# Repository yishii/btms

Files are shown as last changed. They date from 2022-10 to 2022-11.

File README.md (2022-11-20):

# Back To the Meeting Switch (BTMS) 【緊急】会議復帰スイッチ

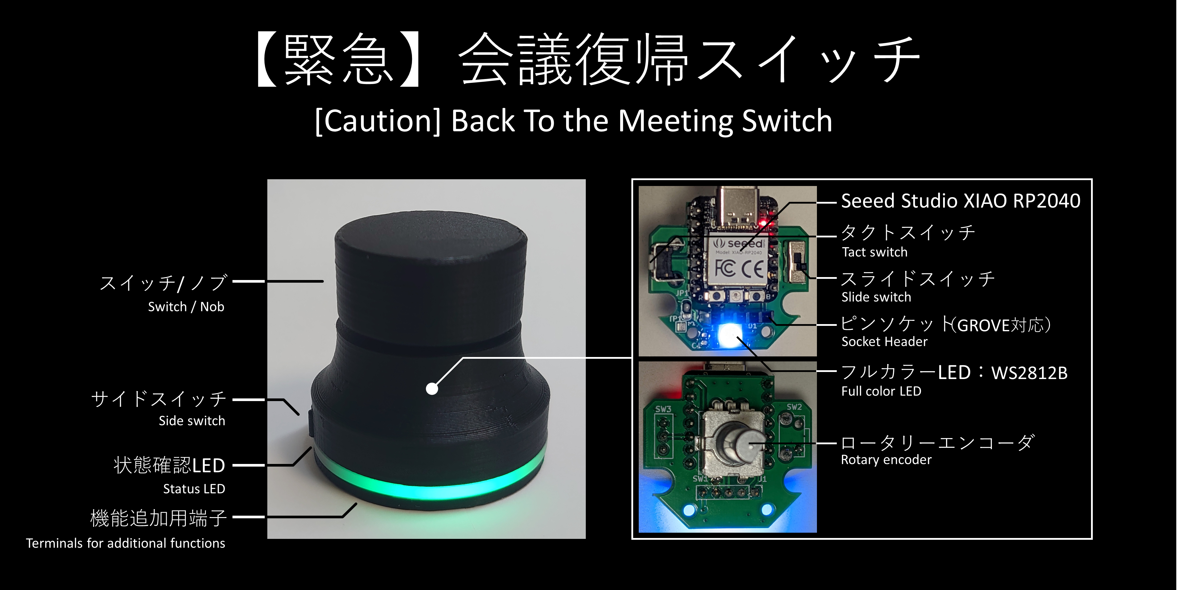
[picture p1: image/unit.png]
BTMS


[[日本語版はこちら]](README_ja.md)

## Back Story
Sometimes happen that attending to the online meeting that roughly just listen to. 
This  is the chance for do editing excel or powerpoints.

But, if suddenly asked some comment unexpectedly, then in panic and cannot back to the meeting right away quickly.

That's why we developed Back To the Meeting Switch(BTMS) for this solution.

With the BTMS, you can turn the knob to select the backgrounded online meeting window, then press the knob the meeting windows comes to the forefront, and at the same time, the MIC mute turns off. And just you do is answer with relax.

So, ~~do another job~~ attend the meeting in peace.

## What is BTMS?

BTMS (Back To the Meeting Switch) is a kind of human interface device that using Seeeduino Xiao (SAMD or RP2040).
With this item, we can get back to online meeting right away even though we're doing other things during the online meeting. This is the main purpose of this device. But this has expansion port (compatible with Grove connector)  at the back side of this device and can easily attach some external button as the Dock of BTMS.

For details, plase watch the video below!

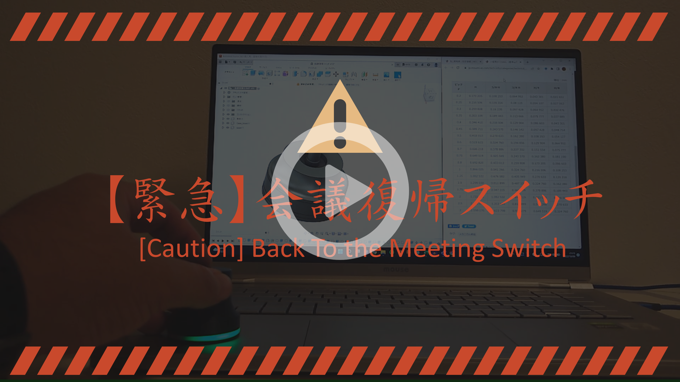
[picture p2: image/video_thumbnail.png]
'Video' (https://youtu.be/crL1nfsBAuw)


## The mechanism

The main operation of this device is just rotate and push the knob. When rotate the knob, this device sends "Alt+TAB" or "Alt+Shift+TAB" according to the rotating direction of the knob for switch to transit to current online meeting window.

After selected the online meeting window now you are attending to, just press the knob to select the window. And at the same time, this device sends the mute toggle key event (Keyboard shortcut) to the selected application.

Mute toggle event is different per video communication applications (e.g. Microsoft Teams, Zoom or Skype, etc).
(For example, Microsoft Teams uses togging the mute by "Ctrl+Shift+M", for WebEx, "Ctrl+M")

So, user set the current communication application to the BTMS and the device uses application-dedicated mute shortcuts for mute toggle key event.

To select the application, just long-press side tactile switch.

## About the expansion port

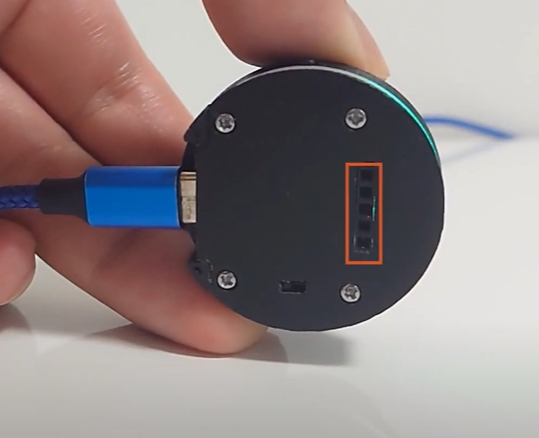
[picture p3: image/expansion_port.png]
Expansion Port


On the bottom side of the device, there is 5 pin connector for expand the functionality of this device.
The signal of this connector is based on Grove connector (I2C), so that many kind of another interface could be added as a dock.

Now we are developing 6-mechanical-keys-dock for application dedicated controller. (For example, send keyevents specialized for Illustrator, Fusion360, etc.)

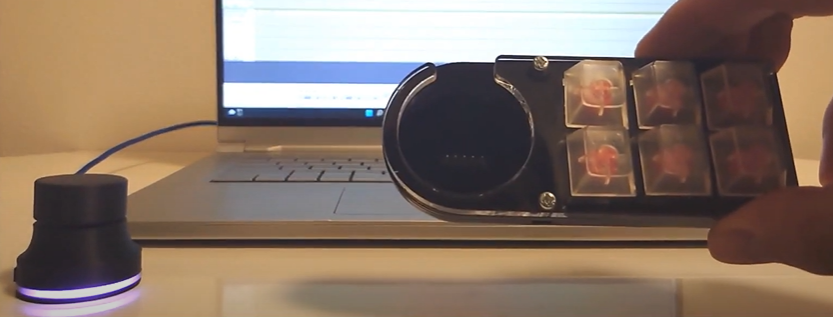
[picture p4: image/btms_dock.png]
6-mechanical-keys-dock


## Resources
In this repository there are 3 folders so far.

- hardware<br>
KiCad Design files and schematic in pdf.
- software<br>
Main sourcecode witten in Python(Circuit Python)

Later we'll add 3D Modeling data that could be print out with 3D Printer.

We'll write step-by-step instruction guide later.

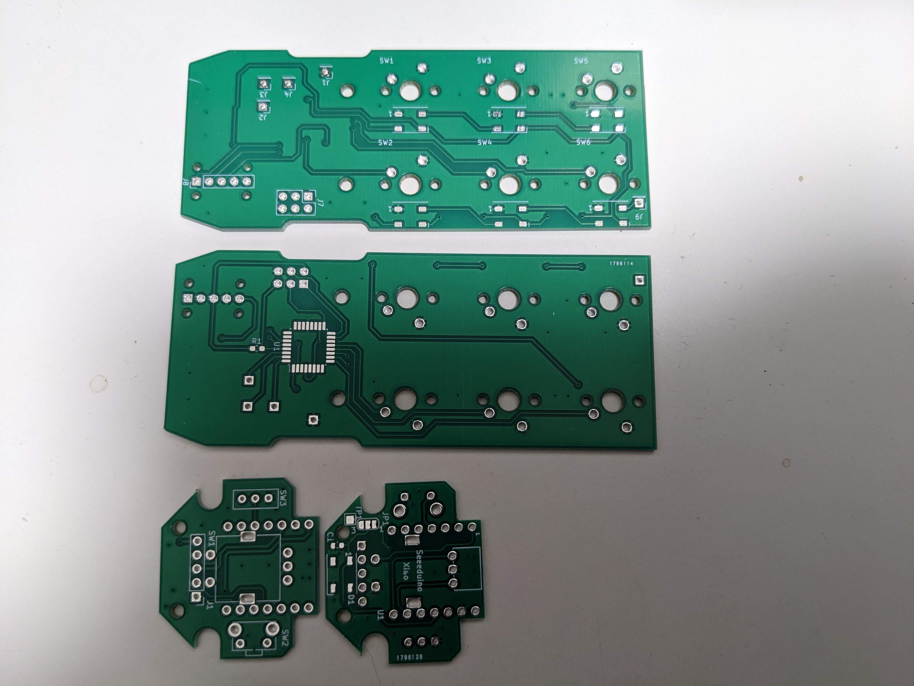
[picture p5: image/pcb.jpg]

This PCBs are created with Seeed FusionPCB!!

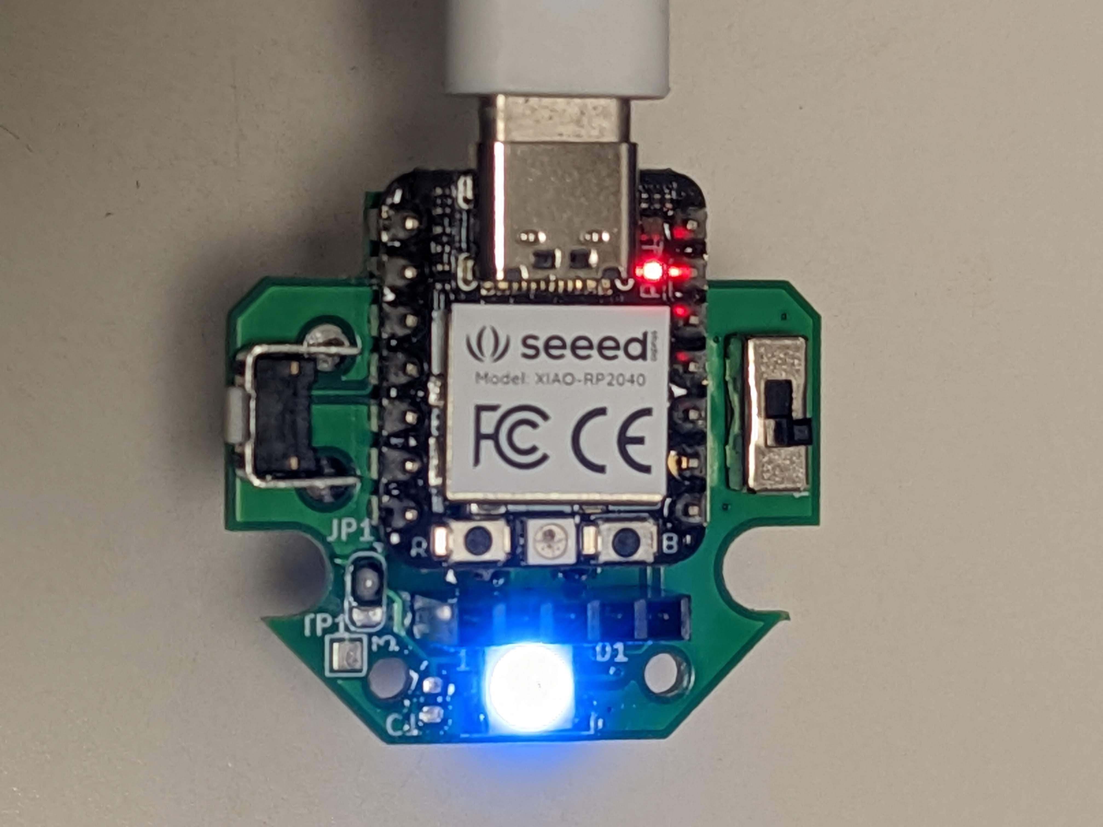
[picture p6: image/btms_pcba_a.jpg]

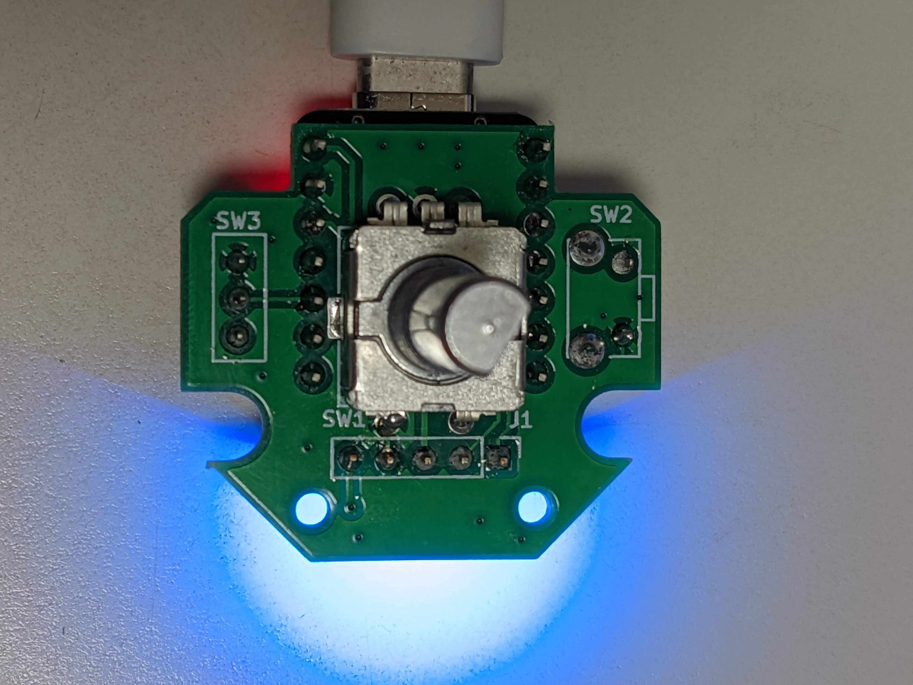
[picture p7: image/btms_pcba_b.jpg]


## Links

1) Seeed XIAO RP2040: https://www.seeedstudio.com/XIAO-RP2040-v1-0-p-5026.html
2) Seeed Fusion PCBA Service: https://www.seeedstudio.com/pcb-assembly.html
3) Seeed Fusion DIY XIAO Mechanical Keyboard Contest: https://www.seeedstudio.com/seeed-fusion-diy-xiao-mechanical-keyboard-contest.html

## Developers
yishii Twitter : https://twitter.com/yishii

dabyoonig Twitter  : https://twitter.com/dabyoong

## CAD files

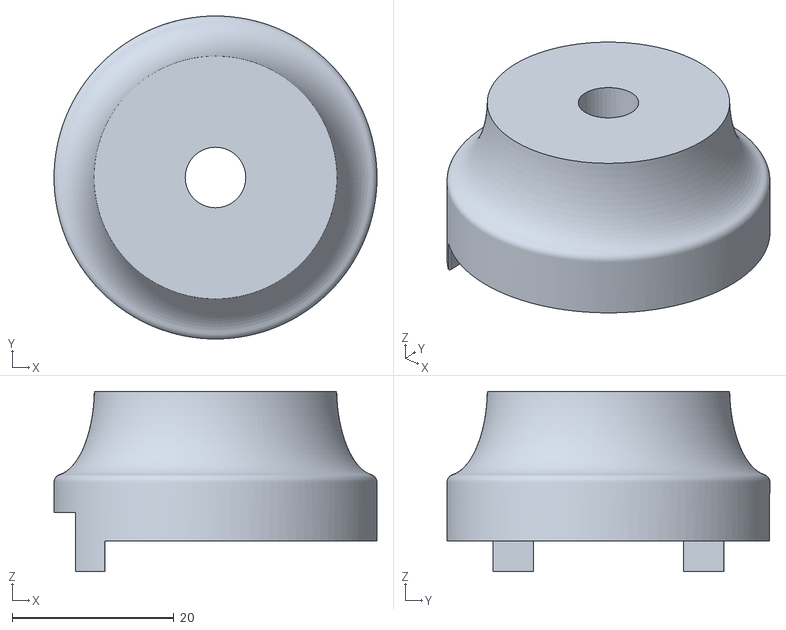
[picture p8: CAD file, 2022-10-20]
case/Upper.stl
40.0 x 40.0 x 22.3

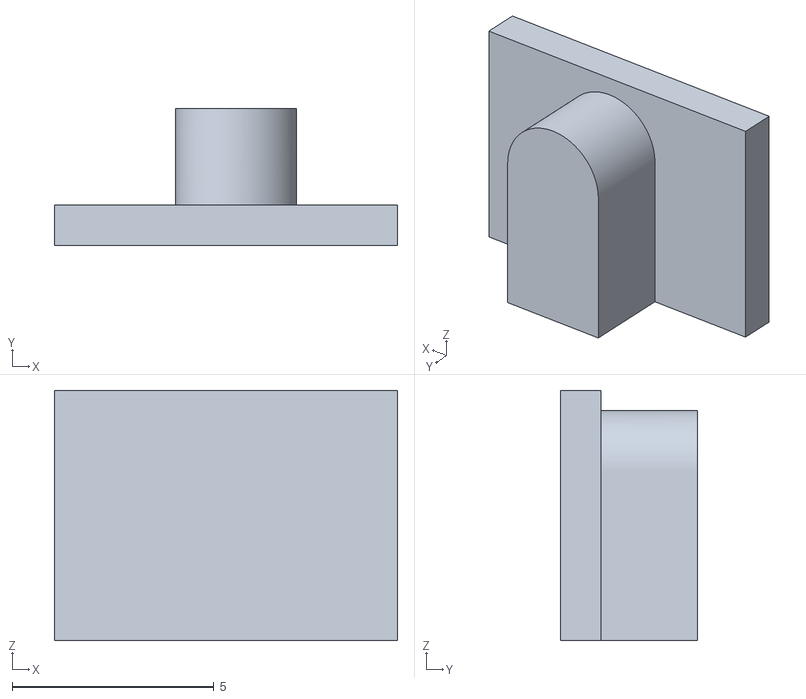
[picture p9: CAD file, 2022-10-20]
case/button.stl
8.50 x 3.40 x 6.20

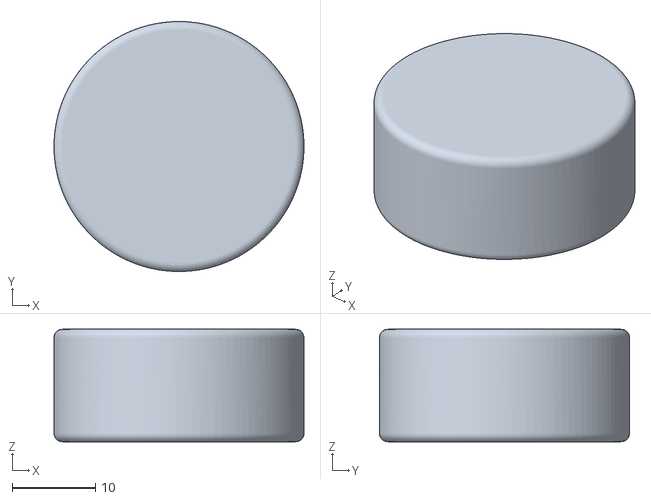
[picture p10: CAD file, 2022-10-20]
case/Nob_0.4.stl
30.0 x 30.0 x 13.5

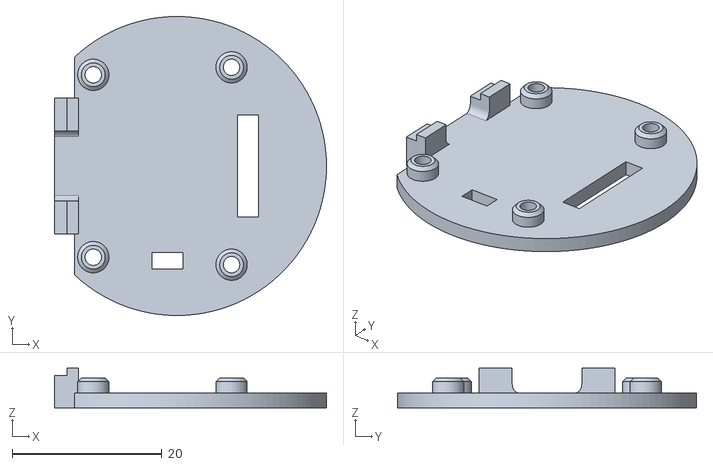
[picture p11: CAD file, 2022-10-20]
case/Lower.stl
36.4 x 40.0 x 5.30

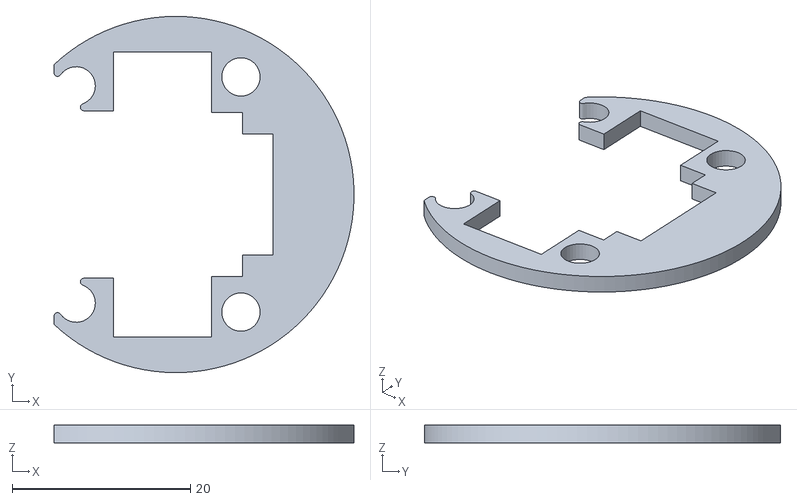
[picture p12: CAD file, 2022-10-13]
case/LightGuide.stl
33.7 x 40.0 x 2.00

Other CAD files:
case/Nob_0.2.stl

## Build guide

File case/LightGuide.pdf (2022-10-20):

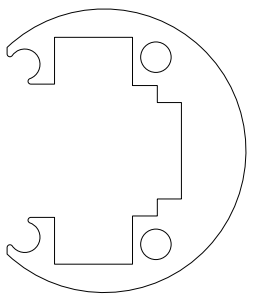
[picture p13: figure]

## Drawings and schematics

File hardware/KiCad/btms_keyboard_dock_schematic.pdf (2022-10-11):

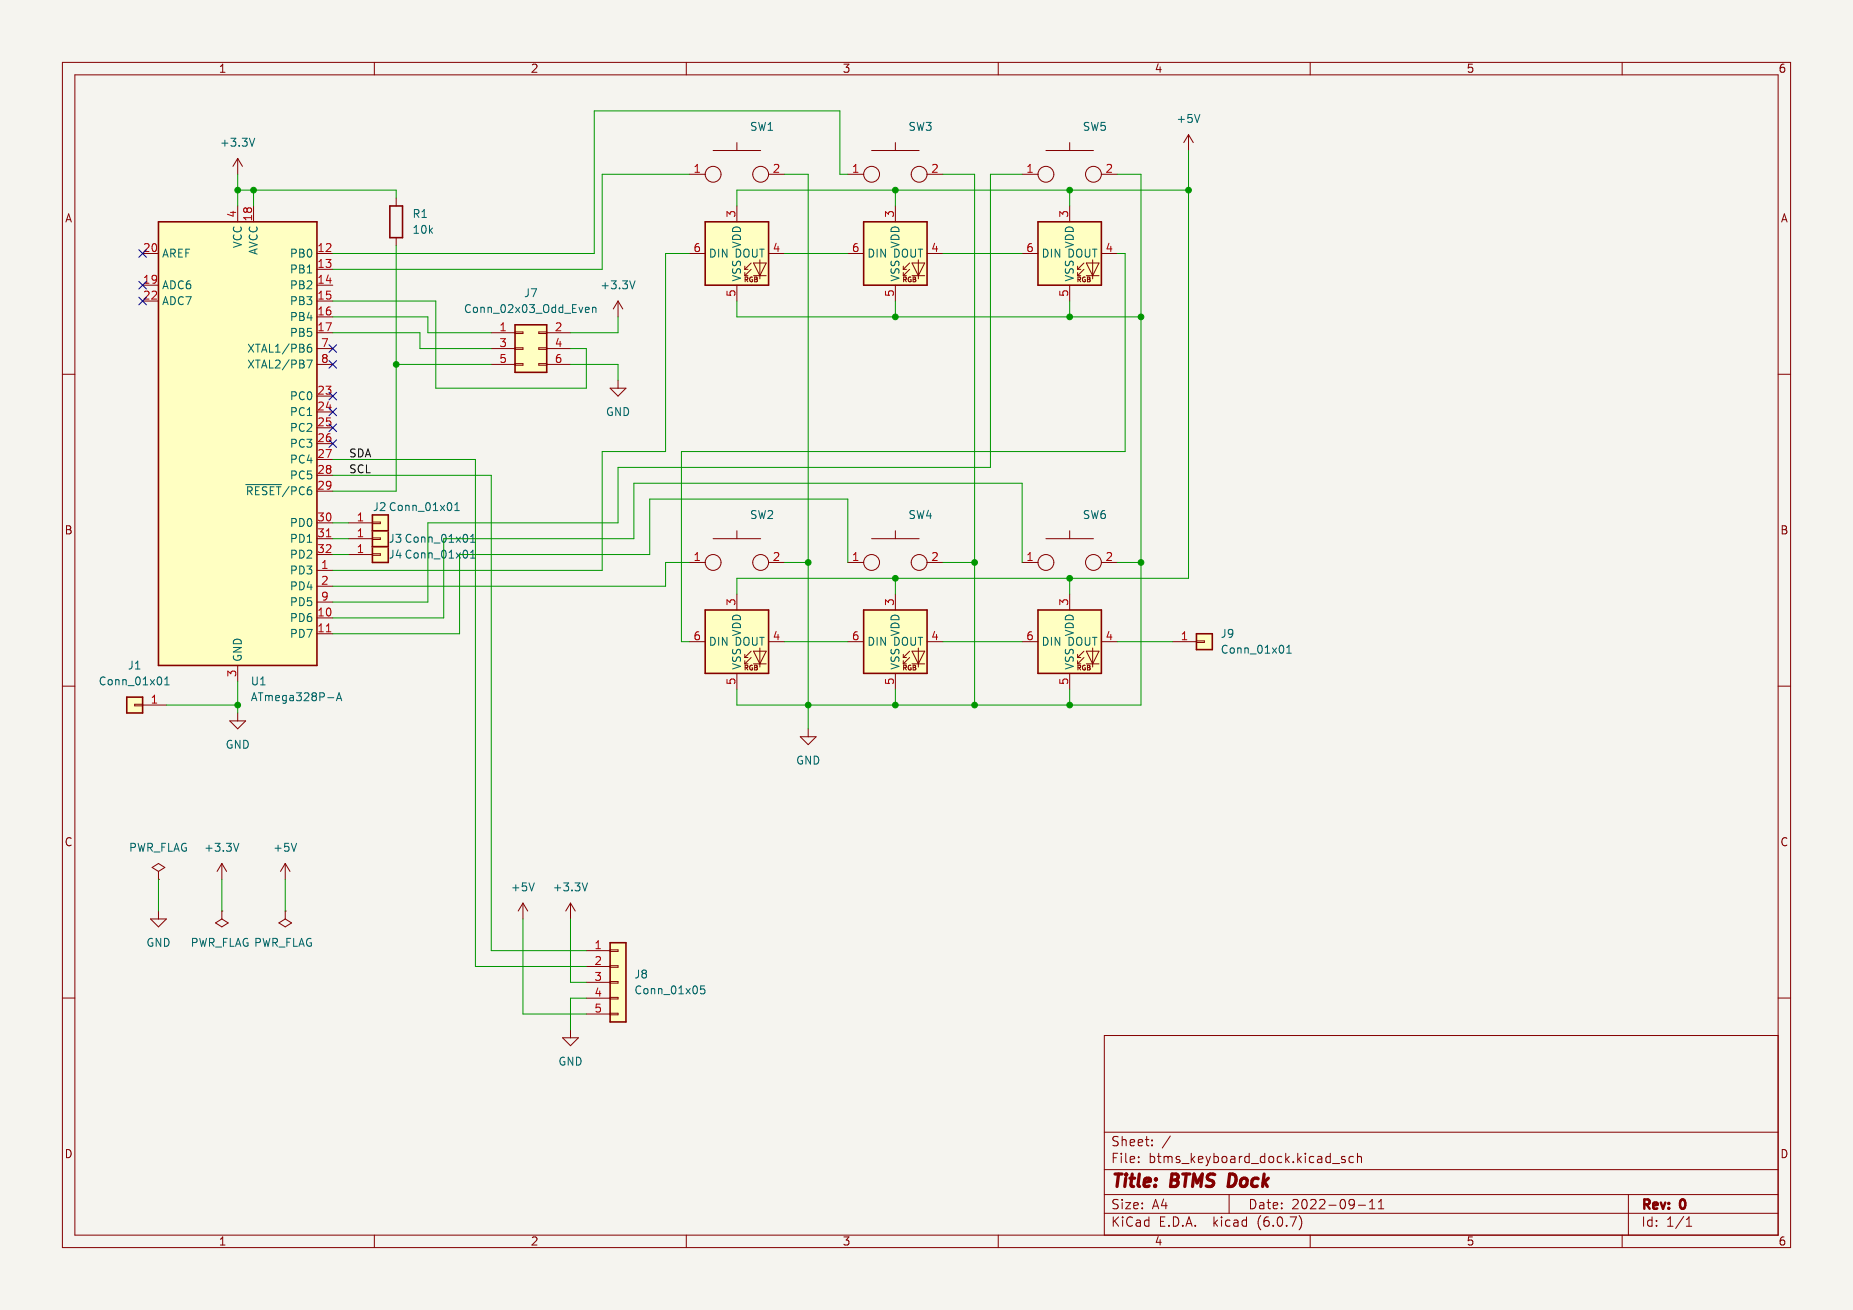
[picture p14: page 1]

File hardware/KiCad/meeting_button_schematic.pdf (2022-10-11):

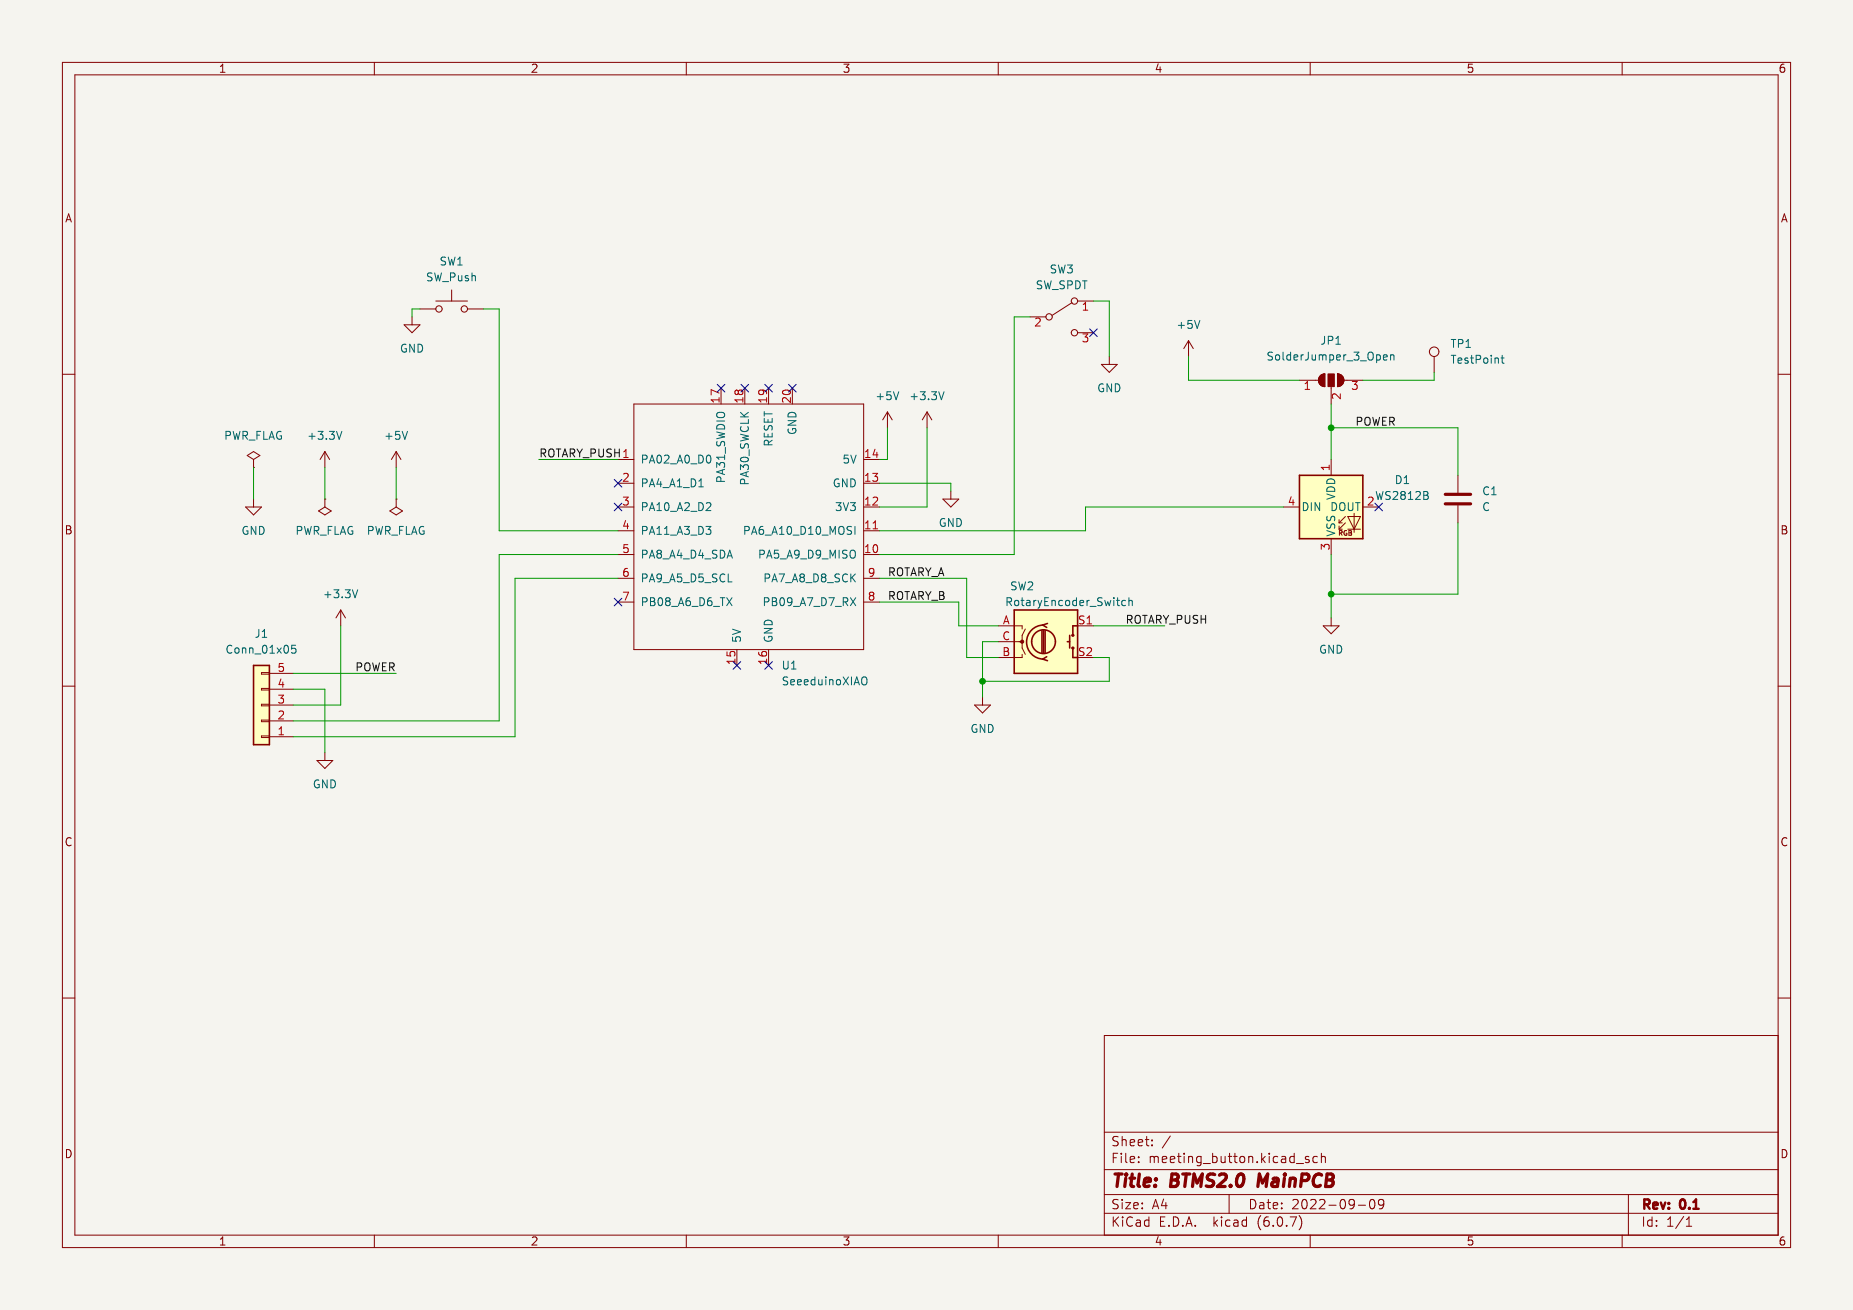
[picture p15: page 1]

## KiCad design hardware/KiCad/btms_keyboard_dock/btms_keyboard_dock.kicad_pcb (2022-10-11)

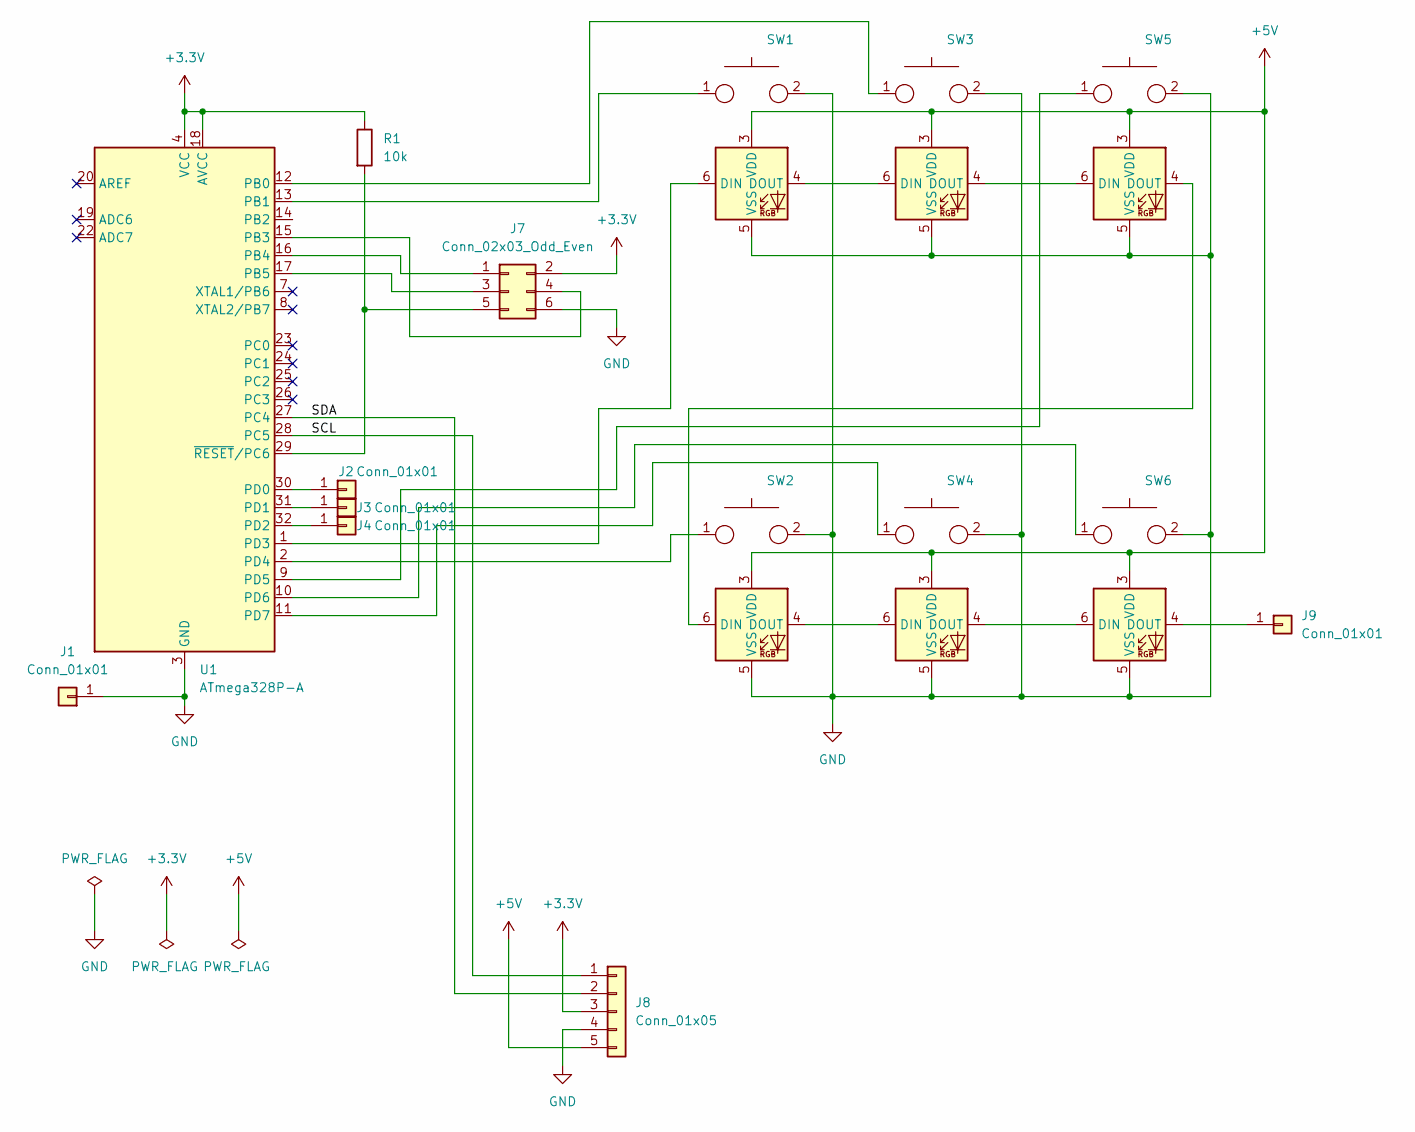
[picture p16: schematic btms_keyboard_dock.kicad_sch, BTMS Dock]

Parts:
J1, J2, J3, J4, J9: Conn_01x01; PinHeader_1x01_P2.54mm_Vertical
J7: Conn_02x03_Odd_Even; PinHeader_2x03_P2.54mm_Vertical
J8: Conn_01x05; PinHeader_1x05_P2.54mm_Vertical
R1: 10k; R_0603_1608Metric_Pad0.98x0.95mm_HandSolder
SW1, SW2, SW3, SW4, SW5, SW6: CherryMX_1Pole_wLED; CherryMX_1Pole_wLED_WS2812B
U1: ATmega328P-A; TQFP-32_7x7mm_P0.8mm

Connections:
+3.3V: J7.2, J8.3, R1.1, U1.4 (VCC), U1.6 (VCC), U1.18 (AVCC)
+5V: J8.5, SW1.3 (VDD), SW2.3 (VDD), SW3.3 (VDD), SW4.3 (VDD), SW5.3 (VDD), SW6.3 (VDD)
/SCL: J8.1, U1.28 (PC5)
/SDA: J8.2, U1.27 (PC4)
GND: J1.1, J7.6, J8.4, SW1.2, SW1.5 (VSS), SW2.2, SW2.5 (VSS), SW3.2, SW3.5 (VSS), SW4.2, SW4.5 (VSS), SW5.2, SW5.5 (VSS), SW6.2, SW6.5 (VSS), U1.3 (GND), U1.5 (GND), U1.21 (GND)
unnamed: J2.1, U1.30 (PD0)
unnamed: J3.1, U1.31 (PD1)
unnamed: J4.1, U1.32 (PD2)
unnamed: J7.1, U1.16 (PB4)
unnamed: J7.3, U1.17 (PB5)
unnamed: J7.4, U1.15 (PB3)
unnamed: J7.5, R1.2, U1.29 (~RESET/PC6)
unnamed: J9.1, SW6.4 (DOUT)
unnamed: SW1.1, U1.13 (PB1)
unnamed: SW1.4 (DOUT), SW3.6 (DIN)
unnamed: SW1.6 (DIN), U1.1 (PD3)
unnamed: SW2.1, U1.2 (PD4)
unnamed: SW2.4 (DOUT), SW4.6 (DIN)
unnamed: SW2.6 (DIN), SW5.4 (DOUT)
unnamed: SW3.1, U1.12 (PB0)
unnamed: SW3.4 (DOUT), SW5.6 (DIN)
unnamed: SW4.1, U1.11 (PD7)
unnamed: SW4.4 (DOUT), SW6.6 (DIN)
unnamed: SW5.1, U1.9 (PD5)
unnamed: SW6.1, U1.10 (PD6)

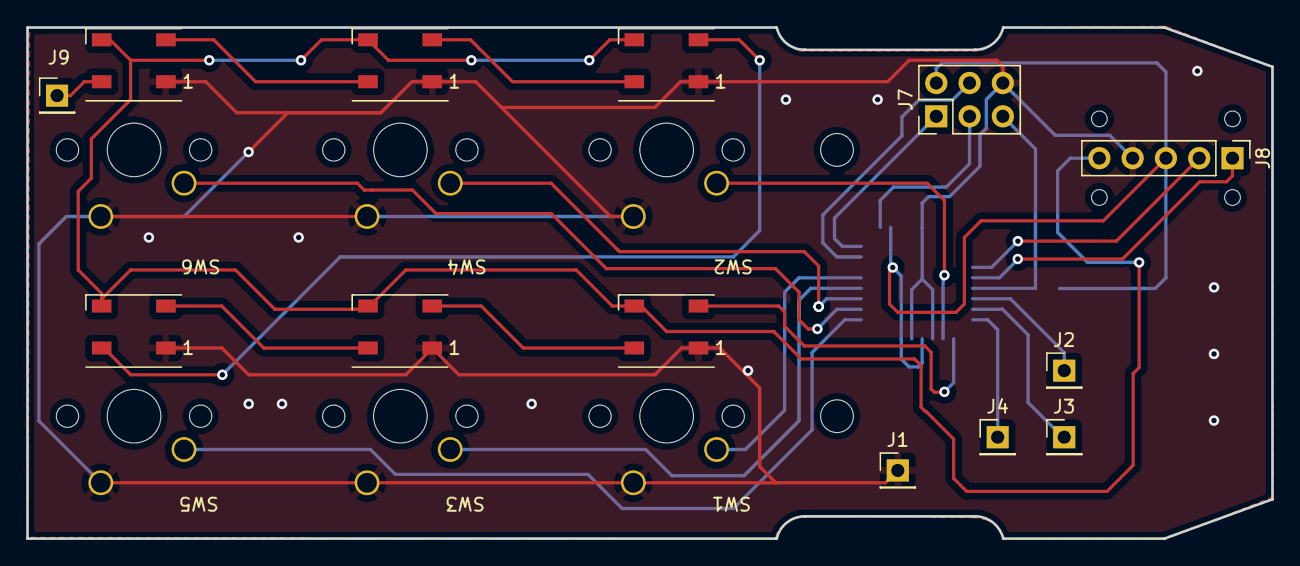
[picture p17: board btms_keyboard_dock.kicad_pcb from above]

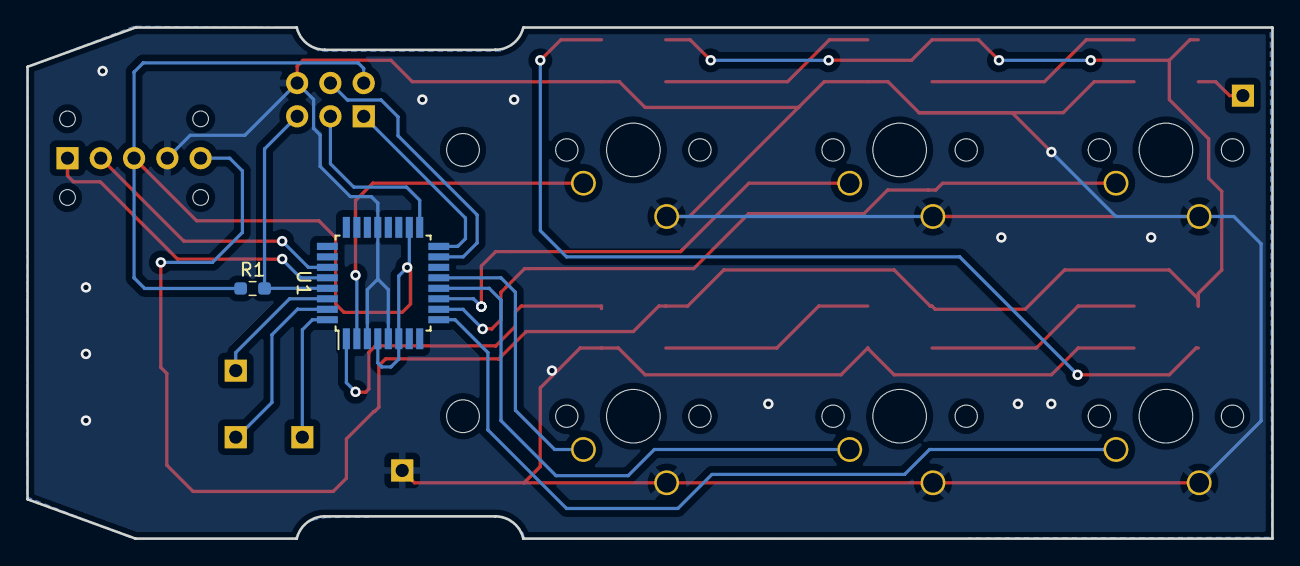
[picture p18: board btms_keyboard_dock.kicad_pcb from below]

Board: 2 copper layers, 95.0 x 39.0 mm, 15 parts (2 on the bottom side), 25 nets.

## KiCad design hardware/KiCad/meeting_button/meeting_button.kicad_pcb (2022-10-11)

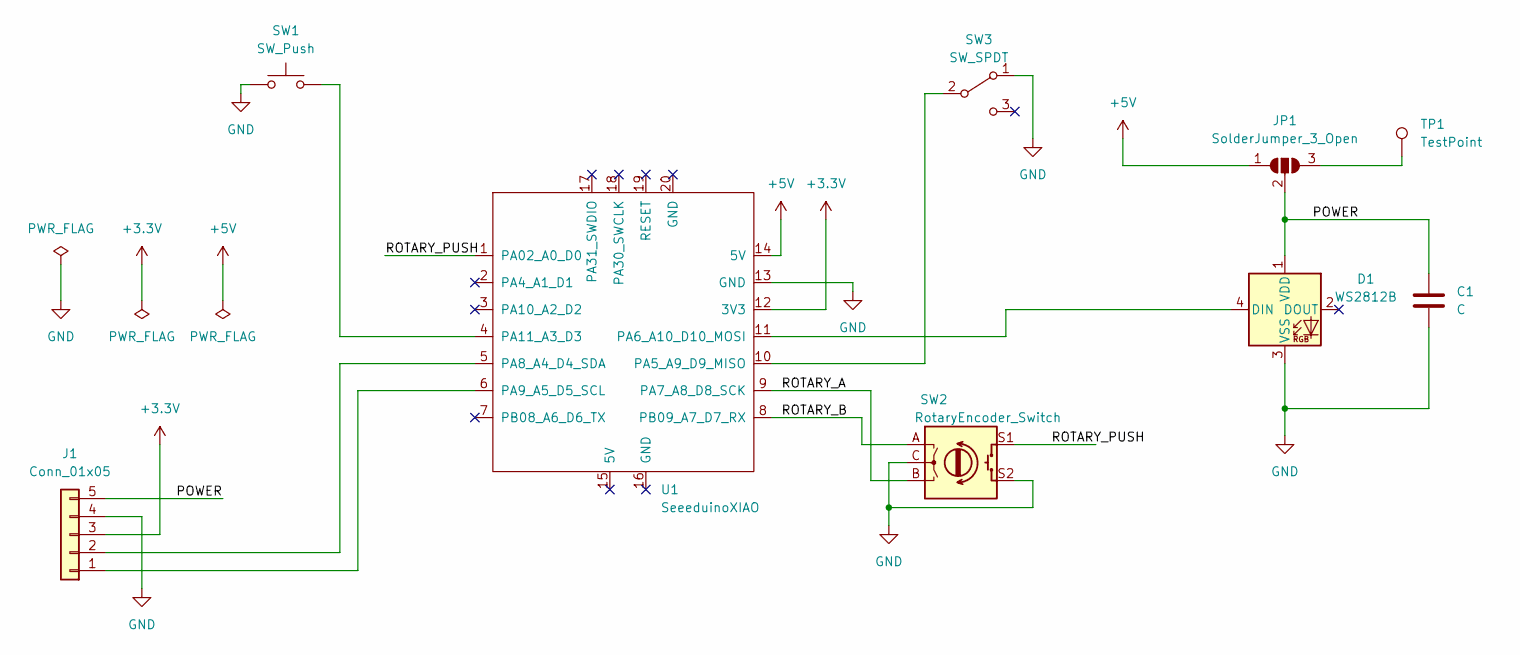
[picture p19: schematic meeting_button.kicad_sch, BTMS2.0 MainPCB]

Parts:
C1: C; C_0603_1608Metric
D1: WS2812B; LED_WS2812B_PLCC4_5.0x5.0mm_P3.2mm
J1: Conn_01x05; PinHeader_1x05_P2.54mm_Vertical
JP1: SolderJumper_3_Open; SolderJumper-3_P1.3mm_Open_RoundedPad1.0x1.5mm_NumberLabels
SW1: SW_Push; TactileSwitch_THBP07-043CB
SW2: RotaryEncoder_Switch; Encoder_Bourns_PEC11L
SW3: SW_SPDT; SlideSwitch_SS-12D00-G5
TP1: TestPoint; TestPoint_Pad_1.5x1.5mm
U1: SeeeduinoXIAO; Seeeduino_Xiao_PinHeader

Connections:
+3.3V: J1.3, U1.12 (3V3)
+5V: JP1.1 (A), U1.14 (5V)
/POWER: C1.1, D1.1 (VDD), J1.5, JP1.2 (C)
/ROTARY_A: SW2.B, U1.9 (PA7_A8_D8_SCK)
/ROTARY_B: SW2.A, U1.8 (PB09_A7_D7_RX)
/ROTARY_PUSH: SW2.S1, U1.1 (PA02_A0_D0)
GND: C1.2, D1.3 (VSS), J1.4, SW1.1, SW2.C, SW2.S2, SW3.1 (A), U1.13 (GND)
unnamed: D1.4 (DIN), U1.11 (PA6_A10_D10_MOSI)
unnamed: J1.1, U1.6 (PA9_A5_D5_SCL)
unnamed: J1.2, U1.5 (PA8_A4_D4_SDA)
unnamed: JP1.3 (B), TP1.1
unnamed: SW1.2, U1.4 (PA11_A3_D3)
unnamed: SW3.2 (B), U1.10 (PA5_A9_D9_MISO)

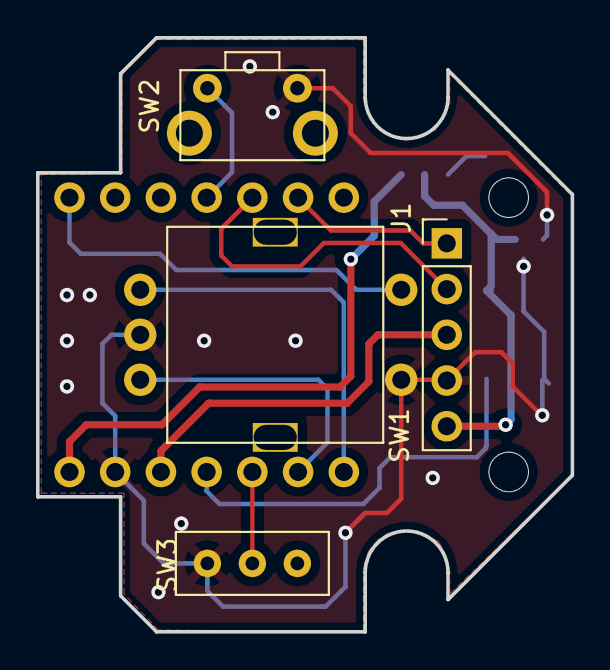
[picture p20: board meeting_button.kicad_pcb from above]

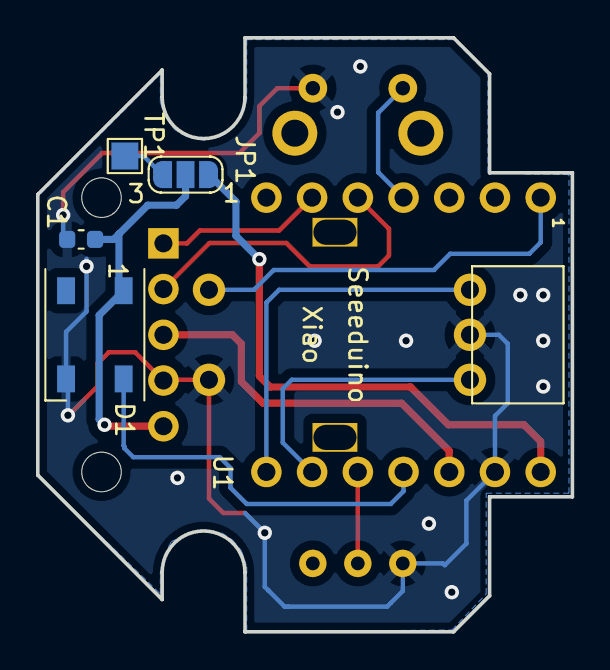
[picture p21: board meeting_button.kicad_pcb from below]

Board: 2 copper layers, 29.7 x 33.0 mm, 9 parts (5 on the bottom side), 13 nets.

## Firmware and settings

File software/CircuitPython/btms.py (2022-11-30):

#
# BTMS for CircuitPython
#
# with Seeeduino Xiao RP2040, use this below;
#  https://circuitpython.org/board/seeeduino_xiao_rp2040/

from board import *
import rotaryio
import digitalio
import time
import usb_hid
from adafruit_hid.keyboard import Keyboard
from adafruit_hid.keycode import Keycode
from neopixel import *
import busio
import usb_cdc
import re
import layers_conf

PIN_A = D7
PIN_B = D8
# PIN_CENTER_PUSH = D2 # for Xiao(SAMD)
PIN_CENTER_PUSH = D0   # for Xiao(RP2040)
# PIN_NEOPIXEL = D6    # for Xiao(SAMD)
PIN_NEOPIXEL = D10     # for Xiao(RP2040)
PIN_TACTILE_SW = D3

PIN_I2C_SCL = D5
PIN_I2C_SDA = D4

I2C_SLAVE_ADDRESS_6BUTTON_KEYDOCK = 0x48

LED_INDICATOR_CHANGE_ONLINE_APPLICATION = 1
LED_INDICATOR_TOGGLE_MUTE_MODE = 2
LED_INDICATOR_SHOW_CURRENT_ONLINE_APPLICATION = 3
LED_INDICATOR_OFF = 100

DOCK_NONE = 0
DOCK_6KEYS = 1

MODE_NORMAL = 0
MODE_WINDOW_CHANGE = 1
MODE_CHANGE_ONLINE_APPLICATION = 2

current_mode = MODE_NORMAL

host_managed_mode = False
btms = {}

class Button:
    gpio = None
    checked_time_last = 1
    pushed_time = 0
    pushed_value_last = True
    on_press_short = None
    on_press_long = None
    after_long_pressed_and_still_pressed = False

    def __init__(self, gpio, on_press_short, on_press_long = None):
        self.gpio = gpio
        self.on_press_short = on_press_short
        self.on_press_long = on_press_long
    
    def poll(self):
        current_time = time.monotonic()
        if current_time > (self.checked_time_last + 0.1):
            self.checked_time_last = current_time
            gpio_value = self.gpio.value
            if (gpio_value == False):
                if self.after_long_pressed_and_still_pressed:
                    return
                self.pushed_time = self.pushed_time + 1
                if (self.pushed_time > 4):
                    if self.on_press_long is not None:
                        self.on_press_long()
                        self.after_long_pressed_and_still_pressed = True
            elif (gpio_value == True) and (self.pushed_value_last == False):
                if self.after_long_pressed_and_still_pressed:
                    self.after_long_pressed_and_still_pressed = False
                else:
                    self.on_press_short()
                self.pushed_time = 0
            self.pushed_value_last = gpio_value

class Layer:
    active_layer_no = 0
    max_application_type = 0
    layers = []
    active_layer = None

    def __init__(self):
        for layer in layers_conf.layers:
            m = __import__(layer)
            m_class = getattr(m, layer)
            m_instance = m_class(btms)
            self.layers += [m_instance]
            self.max_application_type += 1
            print(f'imported module {layer} [{m_instance.target}]')
        self.active_layer = self.layers[self.active_layer_no]

    def get_color(self):
        return self.active_layer.color
    
    def get_target(self):
        return self.active_layer.target
    
    def set_next(self):
        self.active_layer_no = (self.active_layer_no + 1) % self.max_application_type
        self.active_layer = self.layers[self.active_layer_no]
        print(f'Layer changed to {self.active_layer.target}')

    def set_prev(self):
        self.active_layer_no = (self.active_layer_no - 1) % self.max_application_type
        self.active_layer = self.layers[self.active_layer_no]
        print(f'Layer changed to {self.active_layer.target}')

    def mute(self):
        self.active_layer.mute()
    
    def unmute(self):
        self.active_layer.unmute()
    
    def leave(self):
        self.active_layer.leave()

def on_rotate(cw):
    global current_mode, blink_color
    if (current_mode == MODE_NORMAL):
        current_mode = MODE_WINDOW_CHANGE
        kbd.press(Keycode.LEFT_ALT);
    elif (current_mode == MODE_WINDOW_CHANGE):
        pass
    elif (current_mode == MODE_CHANGE_ONLINE_APPLICATION):
        pass

    if current_mode == MODE_WINDOW_CHANGE:
        print('rotate')
        if cw:
            kbd.press(Keycode.SHIFT, Keycode.TAB)
            kbd.release(Keycode.SHIFT, Keycode.TAB)
        else:
            kbd.press(Keycode.TAB)
            kbd.release(Keycode.TAB)
    elif current_mode == MODE_CHANGE_ONLINE_APPLICATION:
        if cw:
            layers.set_next()
            blink_color = layers.get_color()
        else:
            layers.set_prev()
            blink_color = layers.get_color()

rotate_state = 0
last_position = None
def manage_knob():
    global rotate_state
    global last_position
    position = encoder.position # エンコーダーカウント値取得
    if last_position is None:
        last_position = position
    if position != last_position:
        if(position < last_position):
            on_rotate(True)
        elif(position > last_position):
            on_rotate(False)
    last_position = position

internal_mute_state = False
def switch_mute_state():
    global internal_mute_state
    if internal_mute_state is True:
        layers.mute()
    else:
        layers.unmute()
    internal_mute_state = True if not internal_mute_state else False
    led_indicate(LED_INDICATOR_TOGGLE_MUTE_MODE)

current_led_color = None
saved_led_color = None
def set_led_color(color):
    global current_led_color
    led[0] = color
    led.show()
    current_led_color = led[0]

def save_led_color():
    global current_led_color
    global saved_led_color
    saved_led_color = current_led_color

def restore_led_color():
    global saved_led_color
    set_led_color(saved_led_color)

led_mode = LED_INDICATOR_OFF
mute_state = False
blink_interval = 1
start_time = 0
blink_state = False
enable_blink = False
blink_color = None

def led_indicate(mode):
    global mute_state, enable_blink, blink_color, blink_interval

    if mode == LED_INDICATOR_CHANGE_ONLINE_APPLICATION:
        blink_interval = 0.1
        blink_color = layers.get_color()
        enable_blink = True
    else:
        enable_blink = False

    if mode == LED_INDICATOR_TOGGLE_MUTE_MODE:
        if mute_state:
            set_led_color((255, 255, 0))
        else:
            set_led_color((255, 100, 0))
        mute_state = False if mute_state else True
    elif mode == LED_INDICATOR_SHOW_CURRENT_ONLINE_APPLICATION:
        save_led_color()
        for _ in range(2):
            set_led_color(layers.get_color())
            time.sleep(0.5)
            set_led_color((0, 0, 0))
            time.sleep(0.5)
        restore_led_color()
    elif mode == LED_INDICATOR_OFF:
        set_led_color((0, 0, 0))

def manage_led():
    global start_time, blink_interval, blink_state, enable_blink, blink_color
    if enable_blink:
        if time.monotonic() > (start_time + blink_interval):
            start_time = time.monotonic()
            if blink_state:
                led[0] = blink_color
            else:
                led[0] = (0, 0, 0)
            led.show()
            blink_state = not blink_state

def on_center_short_press():
    global current_mode
    if current_mode == MODE_NORMAL:
        if host_managed_mode:
            # print('center_short_press')
            usb_cdc.console.write(b'center_short_press\r\n')
        else:
            switch_mute_state()
    elif current_mode == MODE_CHANGE_ONLINE_APPLICATION:
        led_indicate(LED_INDICATOR_SHOW_CURRENT_ONLINE_APPLICATION)
        current_mode = MODE_NORMAL
    elif current_mode == MODE_WINDOW_CHANGE:
        kbd.release(Keycode.LEFT_ALT);
        if host_managed_mode is not True:
            switch_mute_state()
        current_mode = MODE_NORMAL

def on_center_long_press():
    global current_mode
    print('4')
    if current_mode == MODE_NORMAL:
        layers.leave()


def on_side_short_press():
    global current_mode
    print('2')
    if current_mode == MODE_NORMAL:
        led_indicate(LED_INDICATOR_SHOW_CURRENT_ONLINE_APPLICATION)

def on_side_long_press():
    global current_mode
    print('3')
    if current_mode == MODE_NORMAL:
        current_mode = MODE_CHANGE_ONLINE_APPLICATION
        save_led_color()
        led_indicate(LED_INDICATOR_CHANGE_ONLINE_APPLICATION)

def on_attach_dock(dock_type):
    print('New dock :' + str(dock_type))
    if dock_type == DOCK_6KEYS:
        print('Initialize for 6KEYS DOCK')
        dock6keys.initialize()

attached_dock_type = DOCK_NONE
last_checked_dock_time = 0

def manage_dock():
    global last_checked_dock_time, attached_dock_type
    if (time.monotonic() > last_checked_dock_time + 1):
        try:
            detected_slave_address = i2c.scan().pop()
            if(detected_slave_address == I2C_SLAVE_ADDRESS_6BUTTON_KEYDOCK):
                detected_dock = DOCK_6KEYS
            else:
                detected_dock = DOCK_NONE
            if(detected_dock != attached_dock_type):
                attached_dock_type = detected_dock
                on_attach_dock(attached_dock_type)
            last_checked_dock_time = time.monotonic()
        except IndexError:
            detected_dock = DOCK_NONE

class Dock6Keys:
    on_key_press = None
    last_pressed = 0x00

    def __init__(self, key1, key2, key3, key4, key5, key6):
        self.on_key_press = []
        self.on_key_press += [key1]
        self.on_key_press += [key2]
        self.on_key_press += [key3]
        self.on_key_press += [key4]
        self.on_key_press += [key5]
        self.on_key_press += [key6]

    def initialize(self):
        for led in range(6):
            self.set_led(led, (0, 0, 0))
    
    def set_led(self, led_no, rgb):
        if(led_no < 6):
            i2c.writeto(I2C_SLAVE_ADDRESS_6BUTTON_KEYDOCK, bytes([led_no, rgb[0], rgb[1], rgb[2]]))
    
    def poll(self):
        receive_data = bytearray(1)
        i2c.readfrom_into(I2C_SLAVE_ADDRESS_6BUTTON_KEYDOCK, receive_data)
        pressed = receive_data[0]
        pressed_differs = pressed ^ self.last_pressed
        for key in range(6):
            mask_bit = 1 << key
            if(pressed_differs & mask_bit):
                if (pressed & mask_bit == mask_bit):
                    self.on_key_press[key](True)
                else:
                    self.on_key_press[key](False)
        self.last_pressed = pressed

fn_pressed = False
def on_dock6_key1_press(pressed):
    if pressed:
        dock6keys.set_led(0, (255, 255, 255))
        if fn_pressed:
            kbd.send(Keycode.A)
        else:
            kbd.send(Keycode.F)
    else:
        dock6keys.set_led(0, (0, 0, 0))

def on_dock6_key2_press(pressed):
    if pressed:
        dock6keys.set_led(1, (255, 255, 255))
        if fn_pressed:
            kbd.send(Keycode.B)
        else:
            kbd.send(Keycode.G)
    else:
        dock6keys.set_led(1, (0, 0, 0))

def on_dock6_key3_press(pressed):
    if pressed:
        dock6keys.set_led(2, (255, 255, 255))
        if fn_pressed:
            kbd.send(Keycode.C)
        else:
            kbd.send(Keycode.H)
    else:
        dock6keys.set_led(2, (0, 0, 0))

def on_dock6_key4_press(pressed):
    if pressed:
        dock6keys.set_led(3, (255, 255, 255))
        if fn_pressed:
            kbd.send(Keycode.D)
        else:
            kbd.send(Keycode.I)
    else:
        dock6keys.set_led(3, (0, 0, 0))

def on_dock6_key5_press(pressed):
    if pressed:
        dock6keys.set_led(4, (255, 255, 255))
        fn_pressed = True
    else:
        dock6keys.set_led(4, (0, 0, 0))
        fn_pressed = False

def on_dock6_key6_press(pressed):
    if pressed:
        dock6keys.set_led(5, (255, 255, 255))
        if fn_pressed:
            kbd.send(Keycode.E)
        else:
            kbd.send(Keycode.J)
    else:
        dock6keys.set_led(5, (0, 0, 0))

re_led = re.compile(r'led ([0-9]*) ([0-9]*) ([0-9]*)')

def command_input():
    global host_managed_mode

    if(usb_cdc.console.in_waiting == 0):
        return

    line = usb_cdc.console.readline()
    line = line.decode().replace('\n', '')

    if(line == 'host_manage'):
        host_managed_mode = True
        print('Entered to host-managed mode')
    elif(line == 'device_manage'):
        host_managed_mode = False
        print('Leave from host-managed mode')
    else:
        if host_managed_mode:
            match = re_led.match(line)
            if match:
                color = (int(match.group(1)), int(match.group(2)), int(match.group(3)))
                # print(f'{int(match.group(1))}, {int(match.group(2))}, {int(match.group(3))}')
                set_led_color(color)

if __name__ == "__main__":
    i2c = busio.I2C(PIN_I2C_SCL, PIN_I2C_SDA, frequency=100000)

    while not i2c.try_lock():
        pass

    kbd = Keyboard(usb_hid.devices)
    # エンコーダー・スイッチ類の初期設定
    encoder = rotaryio.IncrementalEncoder(PIN_A, PIN_B)
    
    center_push = digitalio.DigitalInOut(PIN_CENTER_PUSH)
    center_push.direction = digitalio.Direction.INPUT
    center_push.pull = digitalio.Pull.UP
    
    side_push = digitalio.DigitalInOut(PIN_TACTILE_SW)
    side_push.direction = digitalio.Direction.INPUT
    side_push.pull = digitalio.Pull.UP
    
    center_button = Button(center_push, on_center_short_press, on_center_long_press)
    side_button = Button(side_push, on_side_short_press, on_side_long_press)

    # 外部モジュール向けインターフェースの設定
    btms['kbd'] = kbd

    # オンラインアプリケーションの初期化
    layers = Layer()
    
    # 6Keys Dockの初期化
    dock6keys = Dock6Keys(on_dock6_key1_press, on_dock6_key2_press, on_dock6_key3_press, on_dock6_key4_press, on_dock6_key5_press, on_dock6_key6_press)
    
    # NeoPixelの初期設定
    led = NeoPixel(PIN_NEOPIXEL, 1, brightness=1.0)
    led_indicate(LED_INDICATOR_TOGGLE_MUTE_MODE)
    
    usb_cdc.console.timeout = 0.8


    while True:
        manage_knob()
        manage_led()
        manage_dock()
        center_button.poll()
        side_button.poll()
        command_input()
        if (attached_dock_type == DOCK_6KEYS):
            dock6keys.poll()
        

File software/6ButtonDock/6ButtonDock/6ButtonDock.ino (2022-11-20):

#include <Wire.h>
#include <FastLED.h>
#define NUM_LEDS 6
#define DATA_PIN 3

#define I2C_SLAVE_ADDR  0x48

const uint8_t SW_LUT[6] = {
  9, 4, 8, 7, 5, 6
};
const uint8_t LED_LUT[6] = {
  0, 3, 1, 4, 2, 5
};

bool updateLed = false;
CRGB leds[NUM_LEDS];
uint8_t pressedKeys = 0x00;

void requestEvent()
{
  Wire.write(pressedKeys);
}

void receiveEvent(int len)
{
  uint8_t data[4];
  if (len == 4)
  {
    for (int i = 0; i < 4; i++)
    {
      data[i] = Wire.read();
    }
    leds[LED_LUT[data[0]]] = CRGB(data[1], data[2], data[3]);
    updateLed = true;
  } else {
    while (len--) {
      Wire.read();
    }
  }
}

void boot_indicator(void)
{
  int i;
  int j;
  uint16_t b[6] = {0};
  const uint8_t pos_lut[6] = {
    0, 2, 4, 5, 3, 1
  };
  for (i = 0; i < 255; i++) {
    for (j = 0; j < 6; j++) {
      b[j] += j + 1;
      b[j] = b[j] > 255 ? 255 : b[j];
      leds[LED_LUT[pos_lut[j]]] = CRGB(b[j], b[j], b[j]);
    }
    FastLED.show();
    delay(3);
  }
  memset((void*)&b, 0, sizeof(b));
  for (i = 0; i < 255; i++) {
    for (j = 0; j < 6; j++) {
      b[j] += j + 1;
      b[j] = b[j] > 255 ? 255 : b[j];
      leds[LED_LUT[pos_lut[j]]] = CRGB(255 - b[j], 255 - b[j], 255 - b[j]);
    }
    FastLED.show();
    delay(3);
  }
  delay(60);
  for (i = 0; i < 6; i++) {
    leds[i] = CRGB(0, 0, 255);
  }
  FastLED.show();
  delay(50);
  for (i = 0; i < 6; i++) {
    leds[i] = CRGB(0, 0, 0);
  }
  FastLED.show();
  delay(50);
  for (i = 0; i < 6; i++) {
    leds[i] = CRGB(0, 0, 255);
  }
  FastLED.show();
  delay(50);
  for (i = 0; i < 6; i++) {
    leds[i] = CRGB(0, 0, 0);
  }
  FastLED.show();
  delay(50);
}

void setup() {
  Serial.begin(115200);
  Serial.println("resetting");
  FastLED.addLeds<WS2812, DATA_PIN, GRB>(leds, NUM_LEDS);
  FastLED.setBrightness(100);
  int i;
  boot_indicator();
  for (i = 0; i < 6; i++)
  {
    pinMode(SW_LUT[i], INPUT_PULLUP);
    leds[LED_LUT[i]] = CRGB(0, 0, 0);
  }
  FastLED.show();
  Wire.begin(I2C_SLAVE_ADDR);
  Wire.onRequest(requestEvent);
  Wire.onReceive(receiveEvent);
}

void loop()
{
  static int cnt = 0;
  int i;
  uint8_t pressed;
  static uint8_t pressed_last;
  pressed = 0;
  for (i = 0; i < 6; i++)
  {
    if (digitalRead(SW_LUT[i]) == LOW) {
      pressed |= (1 << i);
    }
  }
  if (pressed == pressed_last)
  {
    cnt++;
    if (cnt > 3) {
      noInterrupts();
      {
        pressedKeys = pressed;
      }
      interrupts();
      cnt = 0;
    }
  } else {
    cnt = 0;
  }
  pressed_last = pressed;
  Serial.println(pressedKeys, BIN);

  if (updateLed)
  {
    FastLED.show();
  }
  delay(1);
}

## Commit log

2022-10-11 説明を作成
2022-10-11 YouTubeリンク修正
2022-10-11 もっかい修正
2022-10-11 fix description about instrction guide
    [btms_keyboard_dock.kicad_pcb, btms_keyboard_dock.kicad_sch, meeting_button.kicad_pcb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]
2022-10-11 説明微修正
2022-10-11 画像を更新
2022-10-12 Change pin assignment
2022-10-12 added pcba pictures
2022-10-13 caseのstlをアップ。導光部もstl形式にしています。
    [LightGuide.stl, Lower.stl, Upper.stl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]
2022-10-13 unitの画像を更新
2022-10-13 unit画像をさらに更新
2022-10-13 unit部分を更新した動画に差し替え
2022-10-14 6button dockのテスト用プログラム
2022-10-20 Caseのデータを更新（コネクタ周り、ボタン周り）
    [Lower.stl, Nob_0.2.stl, Nob_0.4.stl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]
2022-10-27 日本語版を追加
2022-10-27 日本語英語ページリンクを更新
2022-11-20 LEDカラーを更新
2022-11-20 Fnキーサポート版コードベースを作成
2022-11-30 各アプリの制御をレイヤクラスと個々のレイヤごとのソースで行うよう改変 アプリモード(PC側から制御する動作モード)用の実装
